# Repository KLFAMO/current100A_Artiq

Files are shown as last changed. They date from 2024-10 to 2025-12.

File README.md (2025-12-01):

# current100A_Artiq
100A current driver compatible with Artiq. At the moment, device is compatible with Sinara package size and includes all Sinara connectors. There is no software compatibility yet.

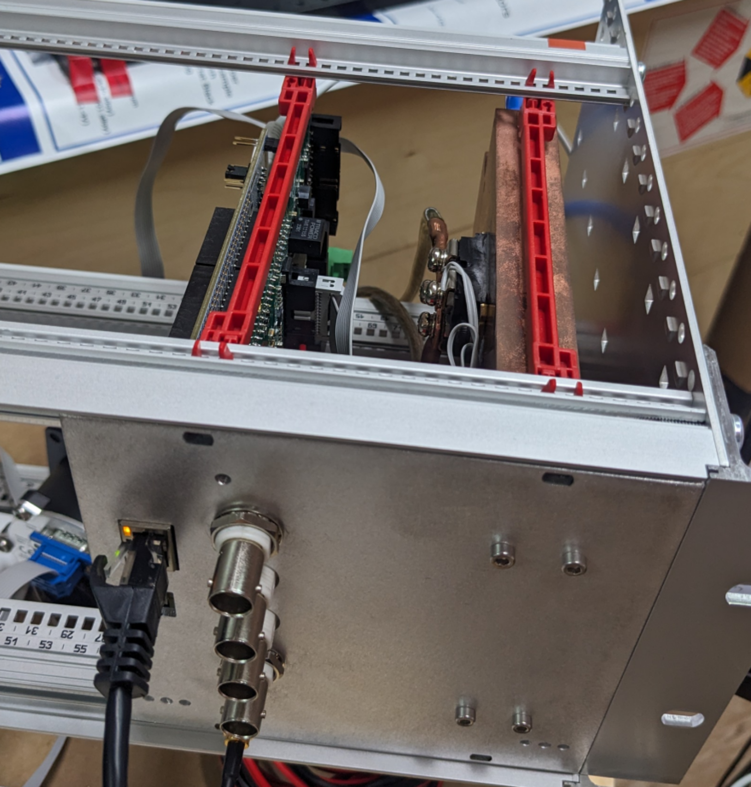
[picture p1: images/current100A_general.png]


## High power circuit

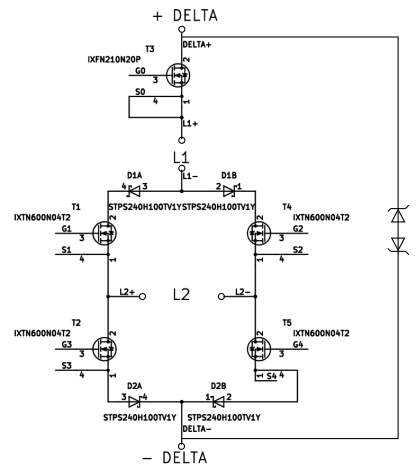
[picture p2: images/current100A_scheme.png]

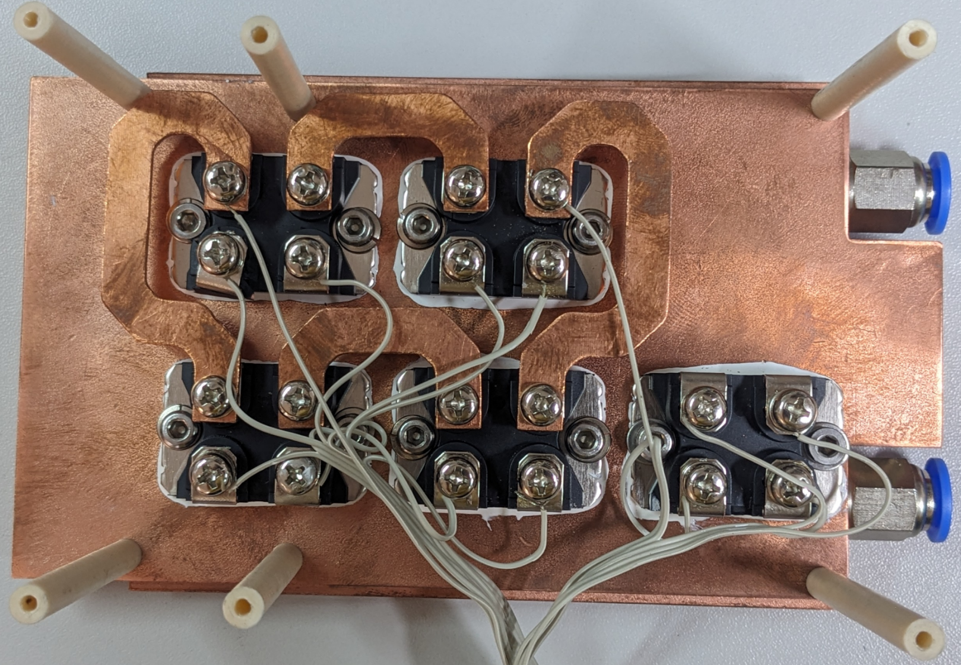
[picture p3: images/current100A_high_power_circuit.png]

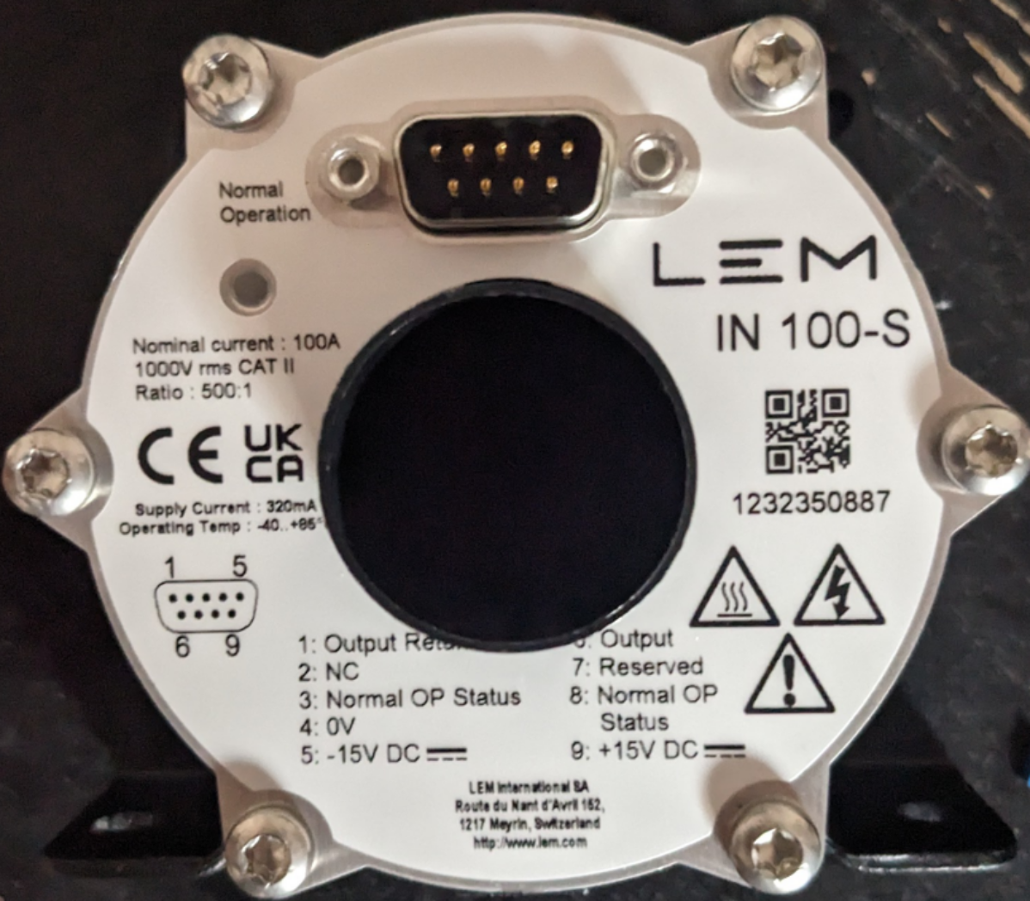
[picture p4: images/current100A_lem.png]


Power supply - two wires (+ and -) from Delta Power Supply. (will be WAGO connector asap).
Warning: 

Coil 1 (L1) - two wires from one coil (will be WAGO connector asap)

Coil 2 (L2) - two wires from second coil (this coil is direction switchable) (will be WAGO connector asap)

LEM IN 100-S is used for current measurement.

## Control board

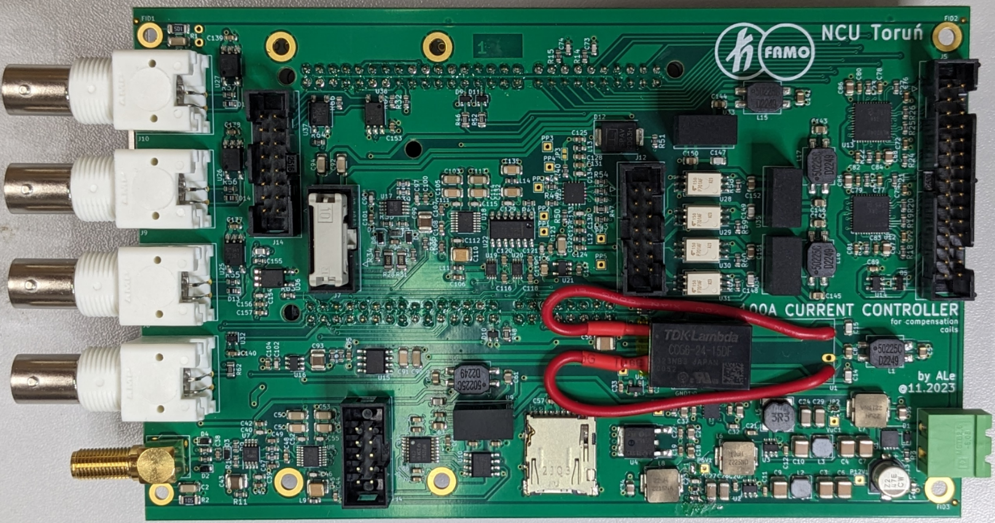
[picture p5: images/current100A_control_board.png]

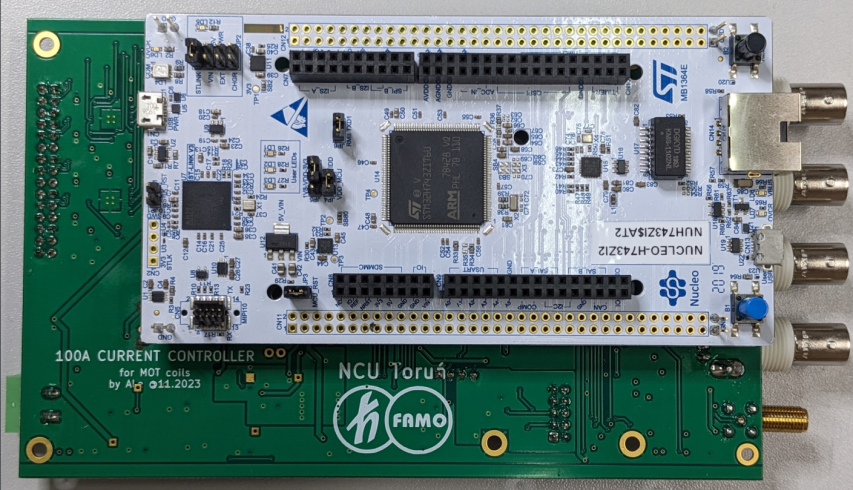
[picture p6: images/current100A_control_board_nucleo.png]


Power supply MSTBA green connector (0 and +12V) for control board.

Ethernet - User Interface communication.

SMA input - (-10V to +10V) current control by voltage (from external control program). 1V -> 10A

4x BNC inputs - not used yet

USB micro - not used yet

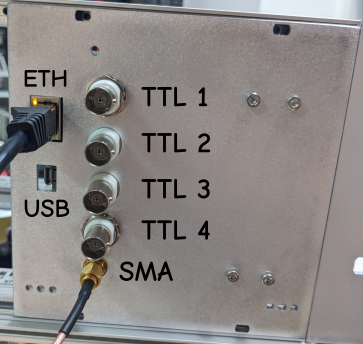
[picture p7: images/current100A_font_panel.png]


# User Interface

User interface is available via TCP/IP on port 10. Depending on configuration IP address is static or taken from DHCP - this must be set when programming uC. After connecting to the device user is able to change setting by sending commands.

## Commands
### Bbasic control

`MODE 0` - switch off current

`MODE 1` - current control via voltage input (SMA input on front panel)

`MODE 2` - current control via ethernet user interface (`CUR` command)

`CUR 10.2` - set current 10.2 A (only in mode 2)

`IMAX 25` - set max possible current value to 25A

`ERMAX 1` - max 1A change in each cycle (0.1ms)

### Advanced settings

`MODE 3` - set gate voltage using `VG` parameter

`I -0.04` - set gain -0.04 (this is bese gain for 50A - it is rescaled by uC for lower current due to udjust transistor characteristics)

`DIR x` - L2 coil current direction (x=-1: current positive, x=1: current negative, x=0: no current - all transistors blocked)

`DST x` - direction switching treshold; current direction switchin in coil L2 is possible only if absolute current value is less than x

`VG` - current gate voltage; in `MODE 3` is set manually

`CALIB 1` - gate voltage - current characteristics callibration. Improves current control.

`CALIB 4` - LEM zero current callibration (automaticaly done during startup)

## License

[MIT](https://opensource.org/licenses/MIT)

# Acknowledgments
This work has received funding from the European Partnership on Metrology, co-financed by the European Union’s Horizon Europe Research and Innovation Programme and by the Participating States, under grant number 22IEM01 TOCK.

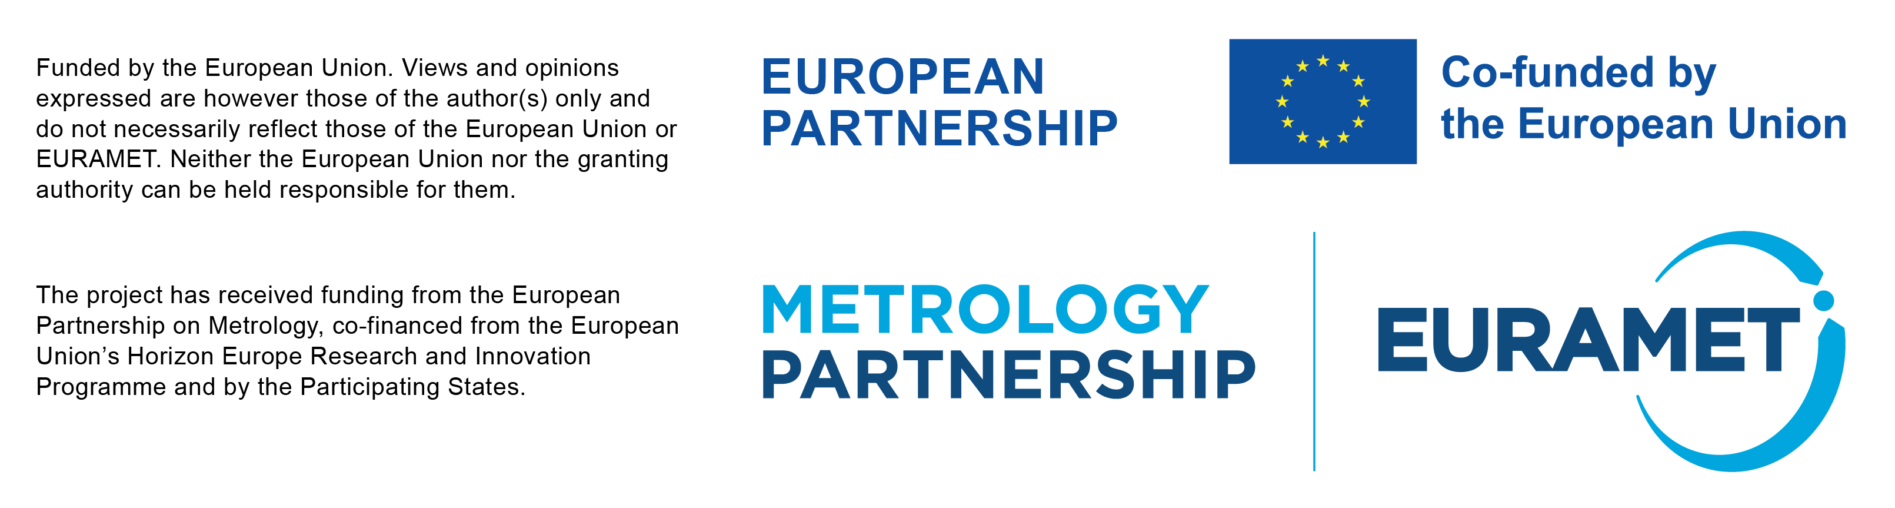
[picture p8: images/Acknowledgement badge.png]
badge


# Issues

Please add your comments in `Issues` Github section (in top of this website).

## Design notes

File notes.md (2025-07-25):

11-09-2024

Current fluctuates around +-10 mA (need to be explainded). On both, Power supply and LEM
V_set |     V_gate  |   I_power_sup |   I_lem_mA
3.130       3.11        0               4
3.180       3.16        0               5
3.270       3.15        0.005           12
3.4         3.38        0.027           33
3.6         3.57        0.180           182
3.7         3.67        0.415           410
3.8         3.77        0.912           880
3.9                     1.88            1820
4.0                     3.96            3376

27-09-2024

controller cycle = 2 ms
meas and sets = 1.17 ms  (TIM7: prescaler=80, period=2000)
for prescaler 80 -> period is measured in us.

single cnv measurement = 1us

changed cycle to 1ms
adc average 200
meas and sets time = 220us

23.10.2024
40A  -  I=-0.015 (ringing)
30A  -  I=-0.019 (ringing)
20A  -  I=-0.025 (ringing)
10A  -  I=-0.042 (ringing)
5A   -  I=-0.077 (ringing)
2A   -  I=-0.18  (ringing)

we set I = -0.01 for 40 A

15-12-2024
new high power circuit with diodes for tock

Vg - I characteristics
cur     vg
0       3.3997
0.5     4.063
1       4.168
1.5     4.234
2       4.283
2.5     4.323
3       4.358
3.5     4.390
4       4.4169
4.5     4.44
5       4.46
6       4.54
7       4.578
8       4.608
9       4.634

10      4.66
11      4.683
12      4.705
13      4.726
14      4.745
15      4.764
16      4.783
17      4.8
18      4.817
19      4.834

20      4.851
21      4.866
22      4.881
23      4.895
24      4.91
25      4.924

02-01-2025
working on shortening cycle time

mode 1 - 140us
mode 2 - 125us
mode 0 - 13us

full cycle set to 200us (before 300us)

switching directions coils using registers instead of hal
mode 1 - 140us
mode 2 - 125us
mode 0 - 13us

----
send_adc_cnvs(100);  - 90.1us
lema = [-0.3110286669, -0.3114823055, -0.3047171740,
-0.3088196444, -0.3112061777, -0.3090366020, -0.3105158581,
-0.3086224103, -0.309214112, -0.3132968597, -0.3124290294]

send_adc_cnvs(50);  - 45.3us
lema = [-0.3115611992, -0.3119162206, -0.3100030493,
-0.3078334736, -0.3146972222, -0.3097860918, -0.3074981756,
-0.3136321578, -0.3098649854, -0.3189180331, -0.3147366690,
-0.3090760488, -0.3099833259, -0.3111667308, -0.3101016664]

send_adc_cnvs(20);  - 18.4us
lema = [-0.3172218194, -0.3297461881, -0.3224485244,
-0.3268271227, -0.3197069697, -0.3215412473, -0.3188785863,
-0.3306337418, -0.3207523107, -0.3178726921, -0.3206536936]

setting send_adc_cnvs(25) -> 22.9us
mode 1 - 73us
mode 2 - 58us
mode 0 - 13us
changing cycle to 110us

----
reading SPI data from ADC
17us

optymalizacja funkcji czytającej (spi still in hal)  ->  15.2us
spi is more complicated to do without hal (I will try to change it later)
the same for adc_set

changed cycle to 100 us
mode 1 - 69.5us
mode 2 - 56us
mode 0 - 13us

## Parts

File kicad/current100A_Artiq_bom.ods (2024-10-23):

Source: | D:\Projekty\FAMO\current100A_Artiq\current100A_Artiq.kicad_sch
Date: | 28.11.2023 11:49:46
Tool: | Eeschema 7.0.1
Generator: | C:\Program Files\KiCad\bin\scripting\plugins/bom_csv_grouped_by_value.py
Component Count: | 311
Item | Qty | Reference(s) | Value | Footprint | Datasheet | Comm
1 | 43 | C11, C12, C19, C20, C21, C22, C30, C31, C33, C36, C57, C58, C60, C64, C65, C67, C68, C71, C72, C75, C76, C77, C78, C79, C80, C81, C82, C83, C84, C89, C116, C118, C120, C121, C130, C131, C136, C137, C138, C139, C140, C153, C156 | 100n 50V X7R | Capacitor_SMD:C_0603_1608Metric | ~
2 | 17 | C23, C39, C40, C46, C52, C55, C97, C98, C102, C111, C112, C115, C126, C129, C133, C134, C154 | 100p 50V C0G | Capacitor_SMD:C_0603_1608Metric | ~
3 | 6 | C38, C47, C49, C96, C107, C109 | 1n 50V C0G | Capacitor_SMD:C_0603_1608Metric | ~
4 | 2 | C73, C74 | 82p 50V C0G | Capacitor_SMD:C_0603_1608Metric | ~
5 | 14 | C41, C42, C44, C95, C100, C101, C104, C106, C117, C124, C125, C127, C128, C157 | GCM188R71E105KA64J | Capacitor_SMD:C_0603_1608Metric | ~ | 1uF 25V X7R
6 | 3 | C66, C69, C70 | GCM188R71E474KA64D | Capacitor_SMD:C_0603_1608Metric | ~ | 470n 25V X7R
7 | 1 | C32 | GRM1885C1H103JA01D | Capacitor_SMD:C_0603_1608Metric | ~ | 10n 50V C0G 5%
8 | 1 | C123 | GRM31C5C1H104JA01L | Capacitor_SMD:C_0603_1608Metric | ~ | 100n 50V C0G
9 | 2 | C48, C108 | 470p 50V C0G | Capacitor_SMD:C_0603_1608Metric_Pad1.08x0.95mm_HandSolder | ~
10 | 6 | C14, C15, C62, C147, C148, C149 | 1n C0G 100V | Capacitor_SMD:C_0805_2012Metric | ~
11 | 1 | C155 | 22n C0G 25V | Capacitor_SMD:C_0805_2012Metric | ~
12 | 1 | C119 | GCM21BR71C335KA73L | Capacitor_SMD:C_0805_2012Metric | ~ | 3,3u >10VDC X7R
13 | 20 | C5, C8, C16, C17, C18, C25, C26, C37, C59, C61, C63, C141, C142, C143, C144, C145, C146, C150, C151, C152 | GRM21BR61E106KA73L | Capacitor_SMD:C_0805_2012Metric | ~ | 10u 25V X5R
14 | 6 | C34, C35, C85, C86, C87, C88 | GRM21BR71A106KA73L | Capacitor_SMD:C_0805_2012Metric | ~ | 10u 10V X7R
15 | 2 | C1, C2 | GCJ31BR73A102KXJ1L | Capacitor_SMD:C_1206_3216Metric | ~
16 | 8 | C50, C53, C90, C92, C94, C103, C113, C122 | GCM31CR71C106KA64L | Capacitor_SMD:C_1206_3216Metric | ~ | 10u X7R 16VDC
17 | 7 | C51, C54, C91, C105, C114, C132, C135 | GRM31C5C1H104JA01L | Capacitor_SMD:C_1206_3216Metric | ~ | 100n 50V C0G
18 | 4 | C24, C27, C28, C29 | GRM31CR71A226KE15L | Capacitor_SMD:C_1206_3216Metric | ~ | 22u 10V X7R Murata
19 | 5 | C3, C4, C6, C7, C56 | 10u X7R 50V | Capacitor_SMD:C_1210_3225Metric | ~ | Murata GRM32ER71H106KA12L
20 | 2 | C45, C110 | 47UF 10V X7R | Capacitor_SMD:C_1210_3225Metric | ~ | 47UF 10V X7R
21 | 3 | C43, C93, C99 | C1210C334J3JACAUTO | Capacitor_SMD:C_1210_3225Metric | ~ | 330n U2J 25V
22 | 2 | C9, C10 | GCM32ER71E106KA57K | Capacitor_SMD:C_1210_3225Metric | ~ | 10u 25V X7R Murata
23 | 1 | C13 | UCW1E470MCL1GS | Capacitor_SMD:CP_Elec_6.3x7.7 |  | >=47u, >=20V, >=5000h, h<9mm
24 | 1 | J3 | DM3AT-SF-PEJM5 | Connector_Card:microSD_HC_Hirose_DM3AT-SF-PEJM5 | https://www.hirose.com/product/document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
25 | 4 | J8, J9, J10, J11 | 5227161-1 | Connector_Coaxial:BNC_Amphenol_B6252HB-NPP3G-50_Horizontal | ~ | 031-5431-10RFX
26 | 1 | J2 | RF2-49B-T-00-50-G-HDW | Connector_Coaxial:SMA_Amphenol_132203-12_Horizontal | ~
27 | 2 | J4, J7 | N2510-6002-RB | Connector_IDC:IDC-Header_2x05_P2.54mm_Vertical | ~
28 | 1 | J12 | N2514-6002RB | Connector_IDC:IDC-Header_2x07_P2.54mm_Vertical | ~
29 | 1 | J14 | N2516-6002-RB | Connector_IDC:IDC-Header_2x08_P2.54mm_Vertical | ~
30 | 1 | J5 | N2530-6002-RB | Connector_IDC:IDC-Header_2x15_P2.54mm_Vertical | ~
31 | 1 | J1 | MSTBA2.5/2-G-5.08 1757242 | Connector_Phoenix_MSTB:PhoenixContact_MSTBA_2,5_2-G-5,08_1x02_P5.08mm_Horizontal | ~
32 | 1 | J13 | L17DAFRA15S | Connectors_DSub:DSUB-15_Female_EdgeMount_Pitch2.77mm | ~ | nie montować, dostarczyć
33 | 1 | J6 | L17DEFRA09S | Connectors_DSub:DSUB-9_Female_EdgeMount_Pitch2.77mm | ~ | nie montować, dostarczyć
34 | 2 | D3, D7 | CZRU52C4V3 | Diode_SMD:D_0603_1608Metric
35 | 3 | D13, D14, D15 | TS4148C RZG | Diode_SMD:D_0603_1608Metric |  | TS4148 RCG
36 | 4 | D2, D4, D6, D8 | TSS40U-RGG | Diode_SMD:D_0603_1608Metric |  | CD0603-B0340R
37 | 1 | D12 | 5.0SMDJ12AS | Diode_SMD:D_SMC | ~
38 | 1 | D1 | SD12C-01FTG | Diode_SMD:D_SOD-323 | https://www.littelfuse.com/~/media/electronics/datasheets/tvs_diode_arrays/littelfuse_tvs_diode_array_sd_c_datasheet.pdf.pdf
39 | 1 | U9 | AM1SS-1203SJZ | ff_lib_7:AM1SS-xxxxS | https://www.aimtec.com/site/Aimtec/files/Datasheet/HighResolution/am1ss-jz.pdf
40 | 3 | U33, U34, U35 | TME1215S | ff_lib_7:AM1SS-xxxxS | https://www.tme.eu/Document/ecc45a2bcbf6e1314ca25a1f4efc1d56/TME-SERIES-EN.pdf
41 | 1 | Q1 | SISS27DN-T1-GE3 | ff_lib_7:Diodes_PowerDI3333-8 | https://www.diodes.com/assets/Datasheets/DMP3007SFG.pdf | SISA01DN-T1-GE3
42 | 5 | L1, L10, L15, L16, L17 | 50225C Murata | ff_lib_7:L_CommonMode_Murata_5000 | https://www.murata-ps.com/pub/data/magnetics/kmp_5000c.pdf | or 50475C
43 | 2 | L2, L3 | LQH44PH220MPRL | ff_lib_7:L_MURATA_LQH44 |  | 22u >0,5A 4x4mm
44 | 1 | M1 | DS1023-2*8S21 | ff_lib_7:MODULE_NUCLEO-F746ZG_mini_M
45 | 1 |  | DS1023-2*10S21
46 | 1 |  | DS1023-2*16S21
47 | 1 |  | DS1023-2*17S21
48 | 1 | U1 | CCG6-12-15DF | ff_lib_7:TDK_DCDC_CCG6_10 | https://product.tdk.com/system/files/dam/doc/product/power/switching-power/dc-dc-converter/catalog/ccg1r5_10_e.pdf | CCG6-24-15DF
49 | 1 | U6 | TPS7A3001DRBx | ff_lib_7:Texas_VSON-8_1EP_3x3mm_P0,65mm_vias | https://www.ti.com/lit/ds/symlink/tps7a30.pdf
50 | 2 | U12, U13 | SN65MLVD040RGZT | ff_lib_7:VQFN-48-1EP_7x7mm_P0.5mm_EP4.1x4.1mm_ThermalVias | https://www.ti.com/lit/ds/symlink/sn65mlvd040.pdf
51 | 1 | U23 | OPA4191xRUMx | ff_lib_7:WQFN-16-1EP_4x4mm_P0.65mm_EP2.7x2.7mm_ThermalVias | https://www.ti.com/lit/ds/symlink/opa4191.pdf
52 | 1 | L4 | BLM18KG331SN1D | Inductor_SMD:L_0603_1608Metric |  | Murata
53 | 5 | L9, L11, L12, L13, L14 | BLM18HE102SN1D | Inductor_SMD:L_0603_1608Metric |  | Murata
54 | 1 | L5 | SRN6045-3R3Y | Inductor_SMD:L_Bourns-SRN6028 |  | 3,3u >3A 6x6mm
55 | 1 | L6 | IHLP2525CZER100M01 | Inductor_SMD:L_Vishay_IHLP-2525 |  | 10u >3A 6,5x6,5mm
56 | 2 | L7, L8 | IHLP2525CZER220M11 | Inductor_SMD:L_Vishay_IHLP-2525 | https://www.vishay.com/docs/34104/ihlp-2525cz-01.pdf
57 | 5 | U25, U26, U27, U36, U38 | TLP2361(TPL,E | Package_SO:MFSOP6-5_4.4x3.6mm_P1.27mm | https://toshiba.semicon-storage.com/info/docget.jsp?did=14229&prodName=TLP2361
58 | 2 | U8, U18 | LTC2380CMS-24#PBF | Package_SO:MSOP-16_3x4mm_P0.5mm | https://www.analog.com/media/en/technical-documentation/data-sheets/238024fa.pdf
59 | 2 | U7, U17 | THS4561IDGKx | Package_SO:MSOP-8_3x3mm_P0.65mm | https://www.ti.com/lit/ds/symlink/ths4561.pdf | LTC1992xMS8#TRPBF, LTC6363xMS8#TRPBF
60 | 1 | U37 | TLP175A | Package_SO:SO-4_4.4x4.3mm_P2.54mm | https://toshiba.semicon-storage.com/info/docget.jsp?did=13665&prodName=TLP175A
61 | 1 | U22 | MAX5719AGSD+ | Package_SO:SOIC-14_3.9x8.7mm_P1.27mm | https://datasheets.maximintegrated.com/en/ds/MAX5717-MAX5719.pdf
62 | 1 | U15 | ADR4540BRZ | Package_SO:SOIC-8_3.9x4.9mm_P1.27mm | https://www.analog.com/media/en/technical-documentation/data-sheets/ADR4520_4525_4530_4533_4540_4550.pdf
63 | 1 | U10 | ADuM121N | Package_SO:SOIC-8_3.9x4.9mm_P1.27mm | https://www.analog.com/media/en/technical-documentation/data-sheets/ADuM120N_121N.pdf
64 | 4 | U28, U29, U30, U31 | TLP701AF(F) | Package_SO:SSO-6_6.8x4.6mm_P1.27mm_Clearance7mm | https://www.tme.eu/Document/18eec4fc8ccc3944788c5600a6539d11/TLP701AFF.pdf
65 | 1 | U11 | MAX3221ExPWR | Package_SO:TSSOP-16_4.4x5mm_P0.65mm | http://www.ti.com/lit/ds/symlink/max3221e.pdf
66 | 2 | U19, U20 | 74LVC2T45DC,125 | Package_SO:VSSOP-8_2.3x2mm_P0.5mm | https://assets.nexperia.com/documents/data-sheet/74LVC_LVCH2T45.pdf
67 | 1 | D5 | WE 8240136 | Package_TO_SOT_SMD:SOT-143 | https://assets.nexperia.com/documents/data-sheet/PRTR5V0U2X.pdf | PRTR5V0U2X
68 | 1 | U5 | AP7313-25SAG-7 | Package_TO_SOT_SMD:SOT-23 | https://www.tme.eu/Document/863c8cbcd42f90a36fcf1f70fe984947/AP7313.pdf
69 | 1 | U14 | 24AA02E48T-I/OT | Package_TO_SOT_SMD:SOT-23-5 | https://ww1.microchip.com/downloads/en/DeviceDoc/24AA02E48-24AA025E48-24AA02E64-24AA025E64-Data-Sheet-20002124H.pdf
70 | 1 | U21 | LP2981-50DBVR | Package_TO_SOT_SMD:SOT-23-5 | http://www.ti.com/lit/ds/symlink/lp2985.pdf
71 | 1 | U16 | ADA4895-1ARJZ | Package_TO_SOT_SMD:SOT-23-6 | https://www.analog.com/media/en/technical-documentation/data-sheets/ADA4807-1_4807-2_4807-4.pdf
72 | 3 | D9, D10, D11 | BAT54SW | Package_TO_SOT_SMD:SOT-323_SC-70 | https://assets.nexperia.com/documents/data-sheet/BAT54W_SER.pdf
73 | 1 | U32 | NL17SZ16DFT2G | Package_TO_SOT_SMD:SOT-353_SC-70-5 | http://www.ti.com/lit/sg/scyt129e/scyt129e.pdf
74 | 1 | U24 | NC7WZ17P6X | Package_TO_SOT_SMD:SOT-363_SC-70-6 | http://www.ti.com/lit/sg/scyt129e/scyt129e.pdf
75 | 1 | U4 | LD29150DT50R | Package_TO_SOT_SMD:TO-252-2 | https://www.st.com/content/ccc/resource/technical/document/datasheet/cc/41/70/73/f5/e6/40/50/CD00003403.pdf/files/CD00003403.pdf/jcr:content/translations/en.C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
76 | 1 | U2 | AP63200WU-7 | Package_TO_SOT_SMD:TSOT-23-6 | https://www.diodes.com/assets/Datasheets/AP63200-AP63201-AP63203-AP63205.pdf
77 | 1 | U3 | AP63203WU-7 | Package_TO_SOT_SMD:TSOT-23-6 | https://www.diodes.com/assets/Datasheets/AP63200-AP63201-AP63203-AP63205.pdf
78 | 12 | R16, R17, R18, R19, R20, R21, R22, R23, R24, R25, R26, R27 | 100R 1% | Resistor_SMD:R_0603_1608Metric | ~
79 | 2 | R29, R30 | 10k 0,1% 10ppm | Resistor_SMD:R_0603_1608Metric | ~ | ERA-3ARB103V, RN73H1JTTD1002B10, RQ73C1J10KBTDF
80 | 4 | R3, R6, R44, R51, R65 | 10k 1% | Resistor_SMD:R_0603_1608Metric | ~
81 | 4 | R58, R59, R60, R61 | 150R 1% | Resistor_SMD:R_0603_1608Metric | ~
82 | 2 | R4, R5 | 196k 1% | Resistor_SMD:R_0603_1608Metric | ~
83 | 16 | R11, R32, R35, R40, R41, R43, R45, R49, R53, R54, R55, R56, R57, R63, R64, R67 | 1k 1% | Resistor_SMD:R_0603_1608Metric | ~
84 | 2 | R14, R15 | 220R 1% | Resistor_SMD:R_0603_1608Metric | ~
85 | 4 | R9, R10, R36, R37 | 2k 1% | Resistor_SMD:R_0603_1608Metric | ~
86 | 1 | R66 | 2k4 1% | Resistor_SMD:R_0603_1608Metric | ~
87 | 4 | R7, R8, R33, R34 | 4,99k 1% | Resistor_SMD:R_0603_1608Metric | ~
88 | 4 | R12, R13, R38, R39 | 49,9R 1% | Resistor_SMD:R_0603_1608Metric | ~
89 | 1 | R50 | 910R 1% | Resistor_SMD:R_0603_1608Metric | ~
90 | 0 | R42 | DNP | Resistor_SMD:R_0603_1608Metric | ~
91 | 5 | R46, R47, R48, R52, R62 | 100R 1% | Resistor_SMD:R_0805_2012Metric | ~
92 | 2 | R1, R2 | HV732BTTD1004F | Resistor_SMD:R_1206_3216Metric | ~
93 | 2 | R28, R31 | RQ73C2B20RBTD | Resistor_SMD:R_1206_3216Metric | ~ | 20R 0,1% 10ppm 0,4W, 3-2176383-0

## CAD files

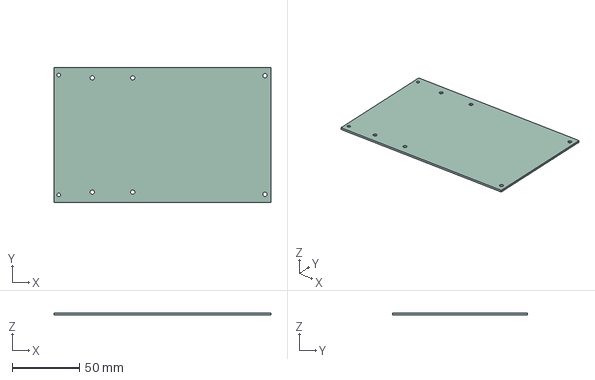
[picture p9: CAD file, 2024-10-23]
kicad/model/artiq_base.step
161.0 x 100.0 x 1.58 mm

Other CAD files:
kicad/model/artiq_base.FCStd

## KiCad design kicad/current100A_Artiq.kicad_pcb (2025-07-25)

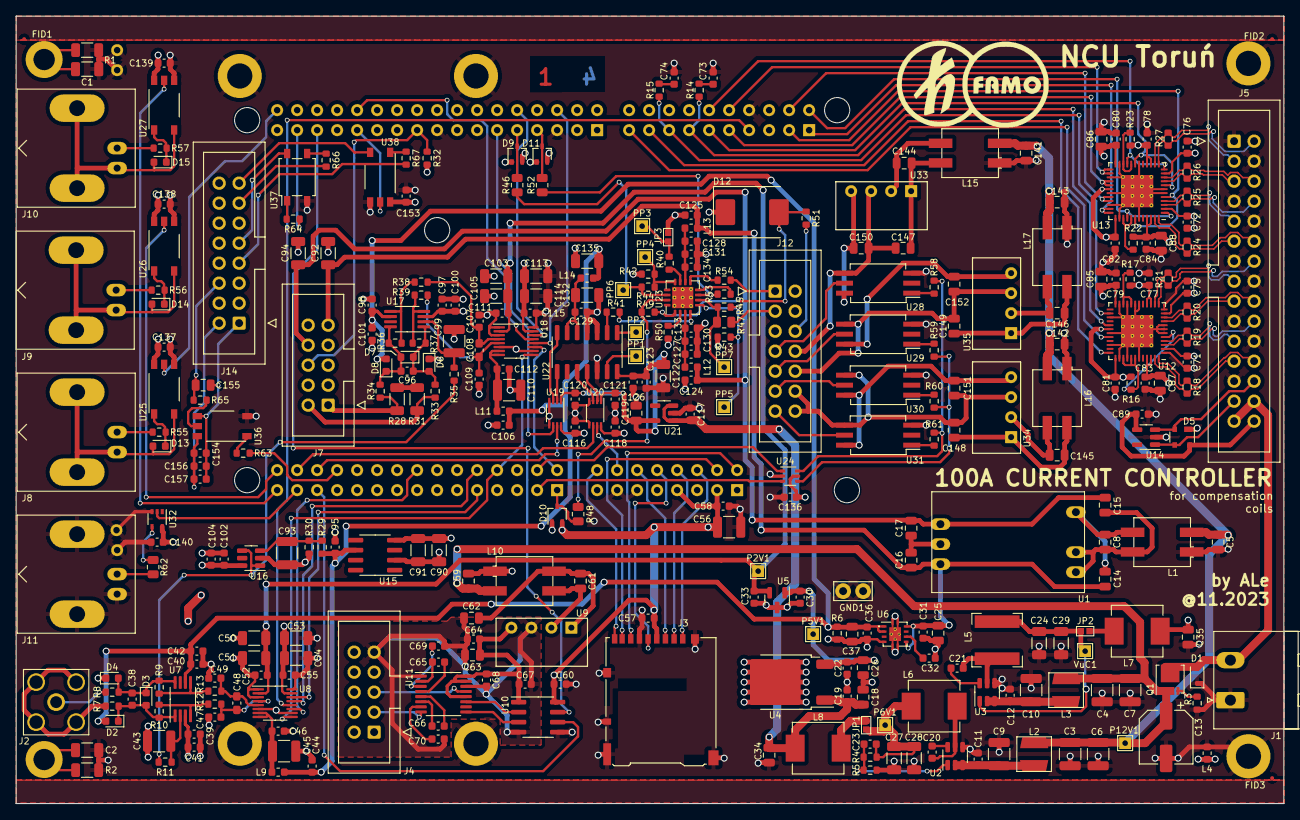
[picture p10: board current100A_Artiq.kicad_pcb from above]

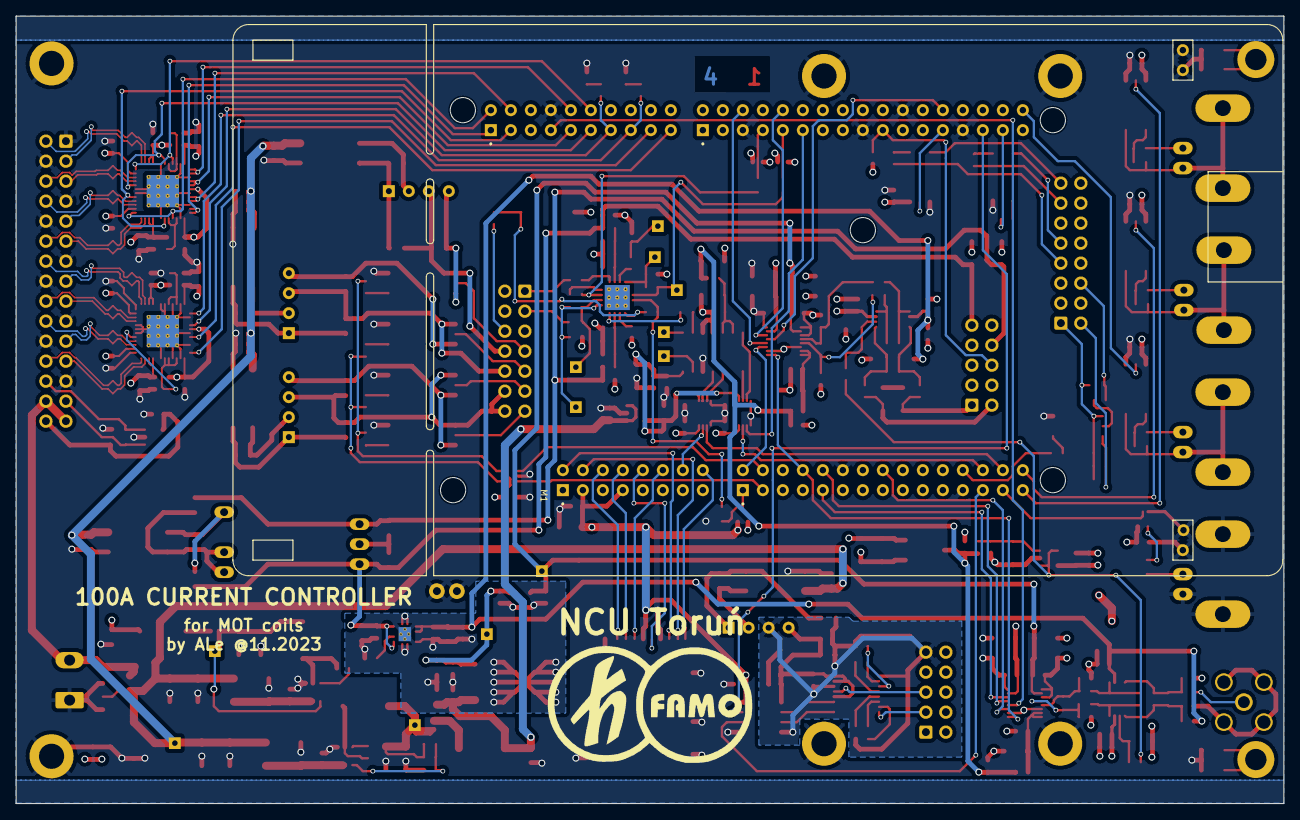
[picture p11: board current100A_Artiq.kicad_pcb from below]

Board: 4 copper layers, 161.0 x 100.0 mm, 337 parts (2 on the bottom side), 210 nets.

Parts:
C1, C2: GCJ31BR73A102KXJ1L; C_1206_3216Metric
C3, C4, C6, C7, C56: 10u X7R 50V; C_1210_3225Metric
C5, C8, C16, C17, C18, C25, C26, C37, C59, C61, C63, C141, C142, C143, C144, C145, C146, C150, C151, C152: GRM21BR61E106KA73L; C_0805_2012Metric
C9, C10: GCM32ER71E106KA57K; C_1210_3225Metric
C11, C12, C19, C20, C21, C22, C30, C31, C33, C36, C57, C58, C60, C64, C65, C67, C68, C71, C72, C75, C76, C77, C78, C79, C80, C81, C82, C83, C84, C89, C116, C118, C120, C121, C130, C131, C136, C137, C138, C139, C140, C153, C156: 100n 50V X7R; C_0603_1608Metric
C13: UCW1E470MCL1GS; CP_Elec_6.3x7.7
C14, C15, C62, C147, C148, C149: 1n C0G 100V; C_0805_2012Metric
C23, C39, C40, C46, C52, C55, C97, C98, C102, C111, C112, C126, C129, C133, C134, C154: 100p 50V C0G; C_0603_1608Metric
C24, C27, C28, C29: GRM31CR71A226KE15L; C_1206_3216Metric
C32: GRM1885C1H103JA01D; C_0603_1608Metric
C34, C35, C85, C86, C87, C88: GRM21BR71A106KA73L; C_0805_2012Metric
C38, C47, C49, C96, C107, C109: 1n 50V C0G; C_0603_1608Metric
C41, C42, C44, C95, C100, C101, C104, C106, C117, C124, C125, C127, C128, C157: GCM188R71E105KA64J; C_0603_1608Metric
C43, C93, C99: C1210C334J3JACAUTO; C_1210_3225Metric
C45, C110: 47UF 10V X7R; C_1210_3225Metric
C48, C108: 470p 50V C0G; C_0603_1608Metric_Pad1.08x0.95mm_HandSolder
C50, C53, C90, C92, C94, C103, C113, C122: GCM31CR71C106KA64L; C_1206_3216Metric
C51, C54, C91, C105, C114, C132, C135: GRM31C5C1H104JA01L; C_1206_3216Metric
C66, C69, C70: GCM188R71E474KA64D; C_0603_1608Metric
C73, C74: 82p 50V C0G; C_0603_1608Metric
C115: 100p C0G 50V; C_0603_1608Metric
C119: GCM21BR71C335KA73L; C_0805_2012Metric
C123: GRM31C5C1H104JA01L; C_0603_1608Metric
C155: 22n C0G 25V; C_0805_2012Metric
D1: SD12C-01FTG; D_SOD-323
D2, D4, D6, D8: TSS40U-RGG; D_0603_1608Metric
D3, D7: CZRU52C4V3; D_0603_1608Metric
D5: WE 8240136; SOT-143
D9, D10, D11: BAT54SW; SOT-323_SC-70
D12: 5.0SMDJ12AS; D_SMC
D13, D14, D15: TS4148C RZG; D_0603_1608Metric
FID1, FID2, FID3: Fiducial; Fiducial_0.5mm_Mask1.5mm
G1: KL_FAMO_LOGO; kl_famo_logo
G2: KL_FAMO_LOGO; kl_famo_logo_small
GND1: PAD; TestPoint_Bridge_Pitch2.54mm_Drill1.0mm
H1, H2: MountingHole_Pad; MountingHole_2.7mm_M2.5_DIN965_Pad
H3, H4, H5, H6, H7, H8: MountingHole_Pad; MountingHole_3.2mm_M3_DIN965_Pad
J1: MSTBA2.5/2-G-5.08 1757242; PhoenixContact_MSTBA_2,5_2-G-5,08_1x02_P5.08mm_Horizontal
J2: RF2-49B-T-00-50-G-HDW; SMA_Amphenol_132203-12_Horizontal
J3: DM3AT-SF-PEJM5; microSD_HC_Hirose_DM3AT-SF-PEJM5
J4, J7: N2510-6002-RB; IDC-Header_2x05_P2.54mm_Vertical
J5: N2530-6002-RB; IDC-Header_2x15_P2.54mm_Vertical
J8: B6252H5-NPP3G-50; BNC_Amphenol_B6252HB-NPP3G-50_Horizontal
J9, J10, J11: 5227161-1; BNC_Amphenol_B6252HB-NPP3G-50_Horizontal
J12: N2514-6002RB; IDC-Header_2x07_P2.54mm_Vertical
J14: N2516-6002-RB; IDC-Header_2x08_P2.54mm_Vertical
JP1, JP2: Jumper_NO_Small; GS2_small
JP3: Jumper_2_Bridged; GS2_small
L1, L10, L15, L16, L17: 50225C Murata; L_CommonMode_Murata_5000
L2, L3: LQH44PH220MPRL; L_MURATA_LQH44
L4: BLM18KG331SN1D; L_0603_1608Metric
L5: SRN6045-3R3Y; L_Bourns-SRN6028
L6: IHLP2525CZER100M01; L_Vishay_IHLP-2525
L7, L8: IHLP2525CZER220M11; L_Vishay_IHLP-2525
L9, L11, L12, L13, L14: BLM18HE102SN1D; L_0603_1608Metric
M1: NUCLEO-H743ZI; MODULE_NUCLEO-F746ZG_mini_M
P2V1, P5V1, P6V1, P12V1: TestPoint; TestPoint_THTPad_1.5x1.5mm_Drill0.7mm
PP1, PP2, PP3, PP4, PP5, PP6, PP7: PAD; TestPoint_THTPad_1.5x1.5mm_Drill0.7mm
Q1: SISS27DN-T1-GE3; Diodes_PowerDI3333-8
R1, R2: HV732BTTD1004F; R_1206_3216Metric
R3, R6, R44, R51, R65: 10k 1%; R_0603_1608Metric
R4, R5: 196k 1%; R_0603_1608Metric
R7, R8, R33, R34: 4,99k 1%; R_0603_1608Metric
R9, R10, R36, R37: 2k 1%; R_0603_1608Metric
R11, R32, R35, R40, R41, R43, R45, R49, R53, R54, R55, R56, R57, R63, R64, R67: 1k 1%; R_0603_1608Metric
R12, R13, R38, R39: 49,9R 1%; R_0603_1608Metric
R14, R15: 220R 1%; R_0603_1608Metric
R16, R17, R18, R19, R20, R21, R22, R23, R24, R25, R26, R27: 100R 1%; R_0603_1608Metric
R28, R31: RQ73C2B20RBTD; R_1206_3216Metric
R29, R30: 10k 0,1% 10ppm; R_0603_1608Metric
R42: DNP; R_0603_1608Metric
R46, R47, R48, R52: 100R 1%; R_0805_2012Metric
R50: 910R 1%; R_0603_1608Metric
R58, R59, R60, R61: 150R 1%; R_0603_1608Metric
R62: 100R; R_0805_2012Metric
R66: 2k4 1%; R_0603_1608Metric
U1: TME1215S; TDK_DCDC_CCG6_10
U2: AP63200WU-7; TSOT-23-6
U3: AP63203WU-7; TSOT-23-6
U4: LD29150DT50R; TO-252-2
U5: AP7313-25SAG-7; SOT-23
U6: TPS7A3001DRBx; Texas_VSON-8_1EP_3x3mm_P0,65mm_vias
U7, U17: THS4561IDGKx; MSOP-8_3x3mm_P0.65mm
U8, U18: LTC2380CMS-24#PBF; MSOP-16_3x4mm_P0.5mm
U9: AM1SS-1203SJZ; AM1SS-xxxxS
U10: ADuM121N; SOIC-8_3.9x4.9mm_P1.27mm
U11: MAX3221ExPWR; TSSOP-16_4.4x5mm_P0.65mm
U12, U13: SN65MLVD040RGZT; VQFN-48-1EP_7x7mm_P0.5mm_EP4.1x4.1mm_ThermalVias
U14: 24AA02E48T-I/OT; SOT-23-5
U15: ADR4540BRZ; SOIC-8_3.9x4.9mm_P1.27mm
U16: ADA4895-1ARJZ; SOT-23-6
U19, U20: 74LVC2T45DC,125; VSSOP-8_2.3x2mm_P0.5mm
U21: LP2981-50DBVR; SOT-23-5
U22: MAX5719AGSD+; SOIC-14_3.9x8.7mm_P1.27mm
U23: OPA4191xRUMx; WQFN-16-1EP_4x4mm_P0.65mm_EP2.7x2.7mm_ThermalVias
U24: NC7WZ17P6X; SOT-363_SC-70-6
U25, U26, U27, U36, U38: TLP2361(TPL,E; MFSOP6-5_4.4x3.6mm_P1.27mm
U28, U29, U30, U31: TLP701AF(F); SSO-6_6.8x4.6mm_P1.27mm_Clearance7mm
U32: NL17SZ16DFT2G; SOT-353_SC-70-5
U33, U34, U35: TME1215S; AM1SS-xxxxS
U37: TLP175A; SO-4_4.4x4.3mm_P2.54mm
VuC1: TestPoint; TestPoint_THTPad_1.5x1.5mm_Drill0.7mm

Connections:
+2V5: C33.2, C50.1, C51.2, C52.1, C103.1, C105.2, C111.1, P2V1.1, U5.2 (VO), U8.2 (VDD), U18.2 (VDD)
+3V3: C35.1, C53.1, C54.2, C55.1, C56.1, C57.1, C58.1, C60.2, C71.1, C72.1, C75.1, C76.1, C77.1, C78.1, C79.1, C80.1, C81.1, C82.1, C83.1, C84.1, C85.1, C86.1, C87.1, C88.1, C113.1, C114.2, C115.1, C116.2, C118.2, C136.1, C137.1, C138.1, C139.1, C140.1, C153.1, D9.2 (K), D10.2 (K), D11.2 (K), J3.4 (VDD), L7.1, M1.CN8_3 (IOREF_CN8), M1.CN8_7 (+3V3_CN8), R16.2, R17.2, R22.2, R23.2, R32.1, U8.15 (OVDD), U10.8 (VDD2), U12.2 (VCC), U12.11 (VCC), U12.15 (VCC), U12.16 (VCC), U12.24 (VCC), U12.30 (PDN), U12.37 (VCC), U12.45 (VCC), U12.46 (VCC), U13.2 (VCC), U13.11 (VCC), U13.15 (VCC), U13.16 (VCC), U13.24 (VCC), U13.30 (PDN), U13.37 (VCC), U13.45 (VCC), U13.46 (VCC), U18.15 (OVDD), U19.8 (VCCB), U20.8 (VCCB), U24.5 (V+), U25.6 (VCC), U26.6 (VCC), U27.6 (VCC), U32.5 (V+), U38.6 (VCC)
+4V: C44.1, C95.1, C106.1, C135.1, L9.1, L11.1, L14.1, R29.1, U15.6 (VOUT)
+5VA: C22.2, C26.1, C30.2, C39.1, C41.1, C90.1, C91.2, C97.1, C100.1, C102.1, C104.1, D4.1 (K), D6.1 (K), P5V1.1, U4.3 (OUT), U5.1 (VI), U7.3 (V+), U15.2 (VIN), U16.6 (V+), U17.3 (V+)
+5VD: C119.1, C120.2, C121.2, C122.1, C123.2, C126.1, U19.1 (VCCA), U20.1 (VCCA), U21.5 (VOUT), U22.14 (VDD)
+6V: C18.1, C19.2, C34.1, C117.1, L8.1, U4.1 (INP), U21.1 (VIN), U21.3 (ON/~OFF)
+12V: C3.1, C4.1, C5.1, C6.1, C7.1, C13.1, C59.1, C141.1, C142.1, C143.1, L1.2, L2.2, L3.2, L10.2, L15.2, L16.2, L17.2, P12V1.1, Q1.1 (S), Q1.2 (S), Q1.3 (S)
+15V: C15.1, C17.2, C94.1, C124.1, J7.8, L12.2, U1.4 (+VOUT)
-15V: C14.1, C16.1, C25.1, C31.1, C92.1, C125.1, J7.9, L13.2, U1.6 (-VOUT), U6.5 (EN), U6.8 (IN)
-VSW: C36.1, C37.1, C40.2, C42.2, C98.2, C101.2, D2.2 (A), D8.2 (A), R6.1, U6.1 (OUT), U6.2 (FB), U7.6 (V-), U17.6 (V-)
/15A_ON: M1.CN9_30 (D64/PG1/IO), U26.5 (VO)
/100A_ON: M1.CN9_29 (D65/PG0/IO), U27.5 (VO)
/ADC_CNV: M1.CN9_8 (D54/PD4/USART_B_RTS), U8.9 (CNV), U18.9 (CNV)
/AUX_SPAN: D9.3 (COM), M1.CN10_9 (A7/PF5/ADC3_IN4), R46.2
/Analog input1/ADC1INM: R9.2, R13.2, U7.5 (-)
/Analog input1/ADC1INP: R10.2, R12.2, U7.4 (+)
/Analog input1/IN_gnd: J2.2 (Ext), R7.1
/Analog input1/VREFB: C45.1, C46.1, L9.2, U8.7 (REF), U8.8 (REF/*DGC)
/Analog input1/VREF_P: R11.2, R35.2, U16.1, U16.4 (-)
/COIL_SPAN: D10.3 (COM), M1.CN9_1 (A0/PA3/ADC123_IN3), R48.2
/DEL_CC: M1.CN10_25 (D31/PE2/QSPI_BK1_IO2), U38.5 (VO)
/DEL_PWM: M1.CN9_24 (D61/PF8/SAI_B_SCK), R63.2
/DEL_RSD: M1.CN10_31 (XD33/PB0/TIMER_D_PWM1), R64.2
/DIR_L2: M1.CN10_34 (D35/PB11/TIMER_C_PWM3), U25.5 (VO)
/Digital inputs/output1/12V_pom4: C144.1, L15.3, U33.2 (+VIN)
/Digital inputs/output1/12V_pom5: C145.1, L16.3, U34.2 (+VIN)
/Digital inputs/output1/12V_pom6: C146.1, L17.3, U35.2 (+VIN)
/Digital inputs/output1/GT1: J12.7, U28.5 (VO)
/Digital inputs/output1/GT2: J12.9, U29.5 (VO)
/Digital inputs/output1/GT3: J12.11, U30.5 (VO)
/Digital inputs/output1/GT4: J12.13, U31.5 (VO)
/Digital inputs/output1/L2_LEFTB: R58.2, R61.2, U24.6
/Digital inputs/output1/L2_RIGHTB: R59.2, R60.2, U24.4
/Digital inputs/output1/ST1: C147.1, C150.2, J12.8, U28.4 (VEE), U33.3 (-VOUT)
/Digital inputs/output1/ST2: C149.1, C152.2, J12.10, U29.4 (VEE), U35.3 (-VOUT)
/Digital inputs/output1/ST3: C148.1, C151.2, J12.12, J12.14, U30.4 (VEE), U31.4 (VEE), U34.3 (-VOUT)
/Digital inputs/output1/VT1: C150.1, U28.6 (VCC), U33.4 (+VOUT)
/Digital inputs/output1/VT2: C152.1, U29.6 (VCC), U35.4 (+VOUT)
/Digital inputs/output1/VT3: C151.1, U30.6 (VCC), U31.6 (VCC), U34.4 (+VOUT)
/Digital inputs/output1/gnd_pom4: C144.2, C147.2, L15.4, U33.1 (-VIN)
/Digital inputs/output1/gnd_pom5: C145.2, C148.2, L16.4, U34.1 (-VIN)
/Digital inputs/output1/gnd_pom6: C146.2, C149.2, L17.4, U35.1 (-VIN)
/Kasli interface/I2C_SCL: D5.3 (I/O2), J5.27, U14.1 (SCL)
/Kasli interface/I2C_SDA: D5.2 (I/O1), J5.26, U14.3 (SDA)
/Kasli interface/LVDS0_N: J5.3, R27.1, U13.14 (4B)
/Kasli interface/LVDS0_P: J5.2, R27.2, U13.13 (4A)
/Kasli interface/LVDS1_N: J5.6, R26.1, U13.10 (3B)
/Kasli interface/LVDS1_P: J5.5, R26.2, U13.9 (3A)
/Kasli interface/LVDS2_N: J5.9, R25.1, U13.4 (2B)
/Kasli interface/LVDS2_P: J5.8, R25.2, U13.3 (2A)
/Kasli interface/LVDS3_N: J5.12, R24.1, U13.48 (1B)
/Kasli interface/LVDS3_P: J5.11, R24.2, U13.47 (1A)
/Kasli interface/LVDS4_N: J5.15, R21.1, U12.14 (4B)
/Kasli interface/LVDS4_P: J5.14, R21.2, U12.13 (4A)
/Kasli interface/LVDS5_N: J5.18, R20.1, U12.10 (3B)
/Kasli interface/LVDS5_P: J5.17, R20.2, U12.9 (3A)
/Kasli interface/LVDS6_N: J5.21, R19.1, U12.4 (2B)
/Kasli interface/LVDS6_P: J5.20, R19.2, U12.3 (2A)
/Kasli interface/LVDS7_N: J5.24, R18.1, U12.48 (1B)
/Kasli interface/LVDS7_P: J5.23, R18.2, U12.47 (1A)
/Kasli interface/P3V3_MP: C89.1, D5.4 (VCC), J5.30, U14.4 (V_{CC})
/L2_LEFT: M1.CN9_4 (D52/PD6/USART_B_RX), U24.1
/L2_RIGHT: M1.CN9_3 (A1/PC0/ADC123_IN10), U24.3
/LEM_ADC: M1.CN10_10 (D3/PE13/TIMER_A_PWM3), U18.14 (SDO)
/LEM_BUSY: M1.CN9_2 (D51/PD7/USART_B_SCLK), U18.11 (BUSY)
/LEM_OK: J7.6, M1.CN10_19 (D28/PD13/QSPI_BK1_IO3), R32.2
/LEM_RDL: M1.CN10_6 (D5/PE11/TIMER_A_PWM2), U18.12 (RDL/SDI)
/LEM_SCK: M1.CN10_26 (D39/PE12/TIMER_A_PWM3N), U18.13 (SCK)
/MOS_CLK: M1.CN9_26 (D62/PF7/SAI_B_MCLK), U19.7 (1B)
/MOS_CS: M1.CN10_11 (A8/PF6/ADC3_IN8), U19.6 (2B)
/MOS_DATA: M1.CN9_28 (D63/PF9/SAI_B_FS), U20.6 (2B)
/MOS_LDAC: M1.CN8_14 (D49/PG2/IO), U20.7 (1B)
/Main Current sensor1/ADC1INM: R37.2, R39.2, U17.4 (+)
/Main Current sensor1/ADC1INP: R36.2, R38.2, U17.5 (-)
/Main Current sensor1/LEM_c: R28.2, R31.1
/Main Current sensor1/LEM_out1: J7.1, R28.1, R34.1
/Main Current sensor1/LEM_out2: J7.2, R31.2, R33.1
/Main Current sensor1/VREFA: C110.1, C112.1, L11.2, U18.7 (REF), U18.8 (REF/*DGC)
/Nucleo-H743ZI1/SCPI_RX: M1.CN9_25 (D67/PD0/CAN_RX), U10.6 (VOB)
/Nucleo-H743ZI1/SCPI_TX: M1.CN10_29 (D32/PA0/TIMER_C_PWM1), U10.7 (VIA)
/Nucleo-H743ZI1/SCPI_interface/12V_pom3: C61.1, L10.3, U9.2 (+VIN)
/Nucleo-H743ZI1/SCPI_interface/VDISO: C63.1, C64.2, C67.2, C68.2, U9.4 (+VOUT), U10.1 (VDD1), U11.12 (FORCEON), U11.15 (VCC), U11.16 (~FORCEOFF)
/Nucleo-H743ZI1/SCPI_interface/VSISO: C62.1, C63.2, C64.1, C67.1, C68.1, C69.1, C70.1, J4.9, U9.3 (-VOUT), U10.4 (GND1), U11.1 (~EN), U11.14 (GND)
/Nucleo-H743ZI1/SCPI_interface/gnd_pom3: C61.2, C62.2, L10.4, U9.1 (-VIN)
/Nucleo-H743ZI1/SD_CK: J3.5 (CLK), M1.CN8_10 (D47/PC12/SDMMC_CK)
/Nucleo-H743ZI1/SD_CMD: J3.3 (CMD), M1.CN8_12 (D48/PD2/SDMMC_CMD)
/Nucleo-H743ZI1/SD_D0: J3.7 (DAT0), M1.CN8_2 (D43/PC8/SDMMC_D0)
/Nucleo-H743ZI1/SD_D1: J3.8 (DAT1), M1.CN8_4 (D44/PC9/SDMMC_D1/I2S_A_CKIN)
/Nucleo-H743ZI1/SD_D2: J3.1 (DAT2), M1.CN8_6 (D45/PC10/SDMMC_D2)
/Nucleo-H743ZI1/SD_D3: J3.2 (DAT3/CD), M1.CN8_8 (D46/PC11/SDMMC_D3)
/Nucleo-H743ZI1/SD_DET: J3.9 (DET_B), M1.CN8_16 (D50/PG3/IO)
/Power grid generation1/3V_out: JP2.1, L7.2
/Power grid generation1/6V_out: JP1.1, L8.2
/Power grid generation1/12V_pom: C10.1, C12.1, L3.1, U3.2 (EN), U3.3 (IN)
/Power grid generation1/12V_pom1: C9.1, C11.1, L2.1, U2.2 (EN), U2.3 (IN)
/Power grid generation1/12V_pom2: C8.1, C14.2, L1.3, U1.3 (+VIN)
/Power grid generation1/gnd_pom: C8.2, C15.2, L1.4, U1.1 (-VIN), U1.2 (RC)
/Power grid generation1/sw_out: C24.1, C29.1, JP2.2, L5.1, U3.1 (FB), VuC1.1
/Power grid generation1/sw_out1: C23.1, C27.1, C28.1, JP1.2, L6.1, P6V1.1, R4.1
/Power grid generation1/switch: C21.1, L5.2, U3.5 (SW)
/Power grid generation1/switch1: C20.1, L6.2, U2.5 (SW)
/SET_ADC: M1.CN9_9 (A4/PC2(PB9)/ADC3_IN12/I2C1_SDA), U8.14 (SDO)
/SET_BUSY: M1.CN9_16 (D57/PE4/SAI_A_FS), U8.11 (BUSY)
/SET_RDL: M1.CN7_7 (D19/PB12/I2S_A_WS), U8.12 (RDL/SDI)
/SET_SCK: M1.CN9_10 (D55/PD3/USART_B_CTS), U8.13 (SCK)
/T0_SPAN: D11.3 (COM), M1.CN10_7 (A6/PF4/ADC3_IN9), R52.2
/TO_C15A: M1.CN9_27 (D66/PD1/CAN_TX), U32.2
DAT4: M1.CN7_10 (D13/PA5/SPI_A_SCK), U13.25 (4D), U13.26 (4R)
DAT4_OUT: M1.CN7_12 (D12/PA6/SPI_A_MISO), U13.12 (4DE), U13.21 (~4RE)
DAT5: M1.CN7_9 (XD20/PA15/I2S_B_WS), U13.28 (3D), U13.29 (3R)
DAT5_OUT: M1.CN7_11 (D21/PC7/I2S_B_MCK), U13.8 (3DE), U13.19 (~3RE)
DAT6: M1.CN7_4 (D14/PB9/I2C_A_SDA), U13.32 (2D), U13.33 (2R)
DAT6_OUT: M1.CN7_3 (D17/PB15/I2S_A_SD), U13.5 (2DE), U13.42 (~2RE)
DAT7: M1.CN7_1 (D16/PC6/I2S_A_MCK), U13.35 (1D), U13.36 (1R)
DAT7_OUT: M1.CN7_2 (D15/PB8/I2C_A_SCL), U13.1 (1DE), U13.40 (~1RE)
DT0: J12.1, R54.2
GND: C1.2, C2.2, C3.2, C4.2, C5.2, C6.2, C7.2, C9.2, C10.2, C11.2, C12.2, C13.2, C24.2, C27.2, C28.2, C29.2, C34.2, C35.2, C53.2, C54.1, C55.2, C56.2, C57.2, C58.2, C59.2, C60.1, C71.2, C72.2, C73.2, C74.2, C75.2, C76.2, C77.2, C78.2, C79.2, C80.2, C81.2, C82.2, C83.2, C84.2, C85.2, C86.2, C87.2, C88.2, C89.2, C113.2, C114.1, C115.2, C116.1, C117.2, C118.1, C119.2, C120.1, C121.1, C122.2, C123.1, C126.2, C136.2, C137.2, C138.2, C139.2, C140.2, C141.2, C142.2, C143.2, C153.2, D1.1 (A1), D5.1 (GND), GND1.1, H3.1, H4.1, H5.1, H6.1, H7.1, H8.1, J1.1, J3.6 (VSS), J3.10 (DET_A), J3.11 (SHIELD), J5.1, J5.4, J5.7, J5.10, J5.13, J5.16, J5.19, J5.22, J5.25, J11.2 (Ext), L1.1, L4.1, L10.1, L15.1, L16.1, L17.1, M1.35 (EXT_GND), M1.CN7_8 (GND_CN7), M1.CN8_11 (GND_CN8), M1.CN8_13 (GND_CN8), M1.CN9_12 (GND_CN9), M1.CN9_23 (GND_CN9), M1.CN10_5 (GND_CN10), M1.CN10_17 (GND_CN10), M1.CN10_22 (GND_CN10), M1.CN10_27 (GND_CN10), R1.2, R2.2, R3.2, R5.2, U2.4 (GND), U3.4 (GND), U8.16 (GND), U10.5 (GND2), U12.1 (1DE), U12.6 (GND), U12.7 (GND), U12.8 (3DE), U12.12 (4DE), U12.18 (GND), U12.19 (~3RE), U12.21 (~4RE), U12.23 (GND), U12.27 (GND), U12.31 (GND), U12.34 (GND), U12.38 (GND), U12.40 (~1RE), U12.43 (GND), U12.49 (EP), U13.6 (GND), U13.7 (GND), U13.18 (GND), U13.23 (GND), U13.27 (GND), U13.31 (GND), U13.34 (GND), U13.38 (GND), U13.43 (GND), U13.49 (EP), U14.2 (V_{SS}), U18.16 (GND), U19.4 (GND), U19.5 (DIR), U20.4 (GND), U20.5 (DIR), U21.2 (GND), U22.12 (DGND), U24.2 (V-), U25.4 (VEE), U26.4 (VEE), U27.4 (VEE), U28.3 (C), U29.3 (C), U30.3 (C), U31.3 (C), U32.3 (V-), U36.3 (C), U37.2, U38.4 (VEE)
GNDA: C16.2, C17.1, C18.2, C19.1, C22.1, C25.2, C26.2, C30.1, C31.2, C32.2, C33.1, C36.2, C37.2, C39.2, C40.1, C41.2, C42.1, C43.2, C44.2, C45.2, C46.2, C47.1, C49.2, C50.2, C51.1, C52.2, C90.2, C91.1, C92.2, C93.2, C94.2, C95.2, C97.2, C98.1, C99.2, C100.2, C101.1, C102.2, C103.2, C104.2, C105.1, C106.2, C107.1, C109.2, C110.2, C111.2, C112.2, C124.2, C125.2, C127.2, C128.1, C129.1, C130.1, C131.2, C132.2, C133.2, C134.1, C135.2, D9.1 (A), D10.1 (A), D11.1 (A), D12.1 (A1), J7.5, J7.7, J12.2, J12.4, JP3.1 (A), L4.2, M1.CN10_3 (AGND_CN10), R6.2, R30.2, R42.2, R43.2, R50.1, U1.5 (COM), U4.2 (GND), U5.3 (GND), U6.4 (GND), U6.9 (EP_1), U8.1 (CHAIN), U8.3 (GND), U8.6 (GND), U8.10 (GND), U15.4 (GND), U16.2 (V-), U18.1 (CHAIN), U18.3 (GND), U18.6 (GND), U18.10 (GND), U22.3 (AGNDF), U22.4 (AGNDS)
GT0: J12.3, R47.1
unnamed: C1.1, H1.1, R1.1
unnamed: C2.1, H2.1, R2.1
unnamed: C73.1, R14.2
unnamed: C74.1, R15.2
unnamed: C38.2, D2.1 (K), D3.2 (A), R7.2, R10.1, U7.1 (-)
unnamed: C38.1, D3.1 (K), D4.2 (A), R8.2, R9.1, U7.8 (+)
unnamed: C96.2, D6.2 (A), D7.1 (K), R33.2, R37.1, U17.1 (-)
unnamed: C96.1, D7.2 (A), D8.1 (K), R34.2, R36.1, U17.8 (+)
unnamed: D12.2 (A2), R49.2, R51.1, U23.1 (-)
unnamed: D13.2 (A), J8.2 (Ext), U25.3 (C)
unnamed: D13.1 (K), R55.2, U25.1 (A)
unnamed: D14.2 (A), J9.2 (Ext), U26.3 (C)
unnamed: D14.1 (K), R56.2, U26.1 (A)
unnamed: D15.2 (A), J10.2 (Ext), U27.3 (C)
unnamed: D15.1 (K), R57.2, U27.1 (A)
unnamed: J2.1 (In), R8.1
unnamed: J4.3, U11.8 (RIN)
unnamed: J4.5, U11.13 (DOUT)
unnamed: J8.1 (In), R55.1
unnamed: J9.1 (In), R56.1
unnamed: J10.1 (In), R57.1
unnamed: J11.1 (In), R62.1
unnamed: C154.2, C155.1, C156.2, C157.2, J14.1, U36.4 (VEE)
unnamed: C154.1, C156.1, C157.1, J14.2, U36.6 (VCC)
unnamed: C155.2, J14.6, R65.1
unnamed: J14.7, R67.1
unnamed: J14.9, U37.4
unnamed: J14.13, R66.1
unnamed: J14.15, U38.3 (C)
unnamed: JP3.2 (B), PP3.1, R40.2
unnamed: PP6.1, R44.1, R46.1, U23.14
unnamed: PP7.1, R45.1, R47.2, U23.6
unnamed: Q1.4 (G), R3.1
unnamed: R48.1, R49.1, U23.15
unnamed: R52.1, R53.1, U23.7
unnamed: R62.2, U32.4
unnamed: R64.1, U37.1
unnamed: R66.2, U37.3
unnamed: C20.2, U2.6 (BST)
unnamed: C23.2, R4.2, R5.1, U2.1 (FB)
unnamed: C21.2, U3.6 (BST)
unnamed: C32.1, U6.6 (NR/SS)
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

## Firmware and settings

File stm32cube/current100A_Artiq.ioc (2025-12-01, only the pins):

Mcu.UserName=STM32H743ZITx
PA1.Signal=ETH_REF_CLK
PA2.Signal=ETH_MDIO
PA7.Signal=ETH_CRS_DV
PB0.GPIO_Label=LD1 [Green Led]
PB0.Signal=GPIO_Output
PB12.GPIO_Label=SET_RDL
PB12.Signal=GPIO_Output
PB13.Signal=ETH_TXD1
PB14.GPIO_Label=LD3 [Red Led]
PB14.Signal=GPIO_Output
PC0.GPIO_Label=L2_RIGHT
PC0.Signal=GPIO_Output
PC1.Signal=ETH_MDC
PC2_C.GPIO_Label=SET_ADC
PC2_C.Signal=SPI2_MISO
PC3_C.Signal=SPI2_MOSI
PC4.Signal=ETH_RXD0
PC5.Signal=ETH_RXD1
PD13.GPIO_Label=LEM_OK
PD13.Signal=GPIO_Input
PD3.GPIO_Label=SET_SCK
PD3.Signal=SPI2_SCK
PD4.GPIO_Label=ADC_CNV
PD4.Signal=GPIO_Output
PD6.GPIO_Label=L2_LEFT
PD6.Signal=GPIO_Output
PD7.GPIO_Label=LEM_BUSY
PD7.Signal=GPIO_Input
PD8.GPIO_Label=STLINK_RX
PD8.Signal=USART3_TX
PD9.GPIO_Label=STLINK_TX
PD9.Signal=USART3_RX
PE1.GPIO_Label=LD2 [Yellow Led]
PE1.Signal=GPIO_Output
PE11.GPIO_Label=LEM_RDL
PE11.Signal=GPIO_Output
PE12.GPIO_Label=LEM_SCK
PE12.Signal=SPI4_SCK
PE13.GPIO_Label=LEM_ADC
PE13.Signal=SPI4_MISO
PE4.GPIO_Label=SET_BUSY
PE4.Signal=GPIO_Input
PE6.Signal=SPI4_MOSI
PF6.GPIO_Label=MOS_CS
PF6.Signal=GPIO_Output
PF7.GPIO_Label=MOS_CLK
PF7.Signal=SPI5_SCK
PF9.GPIO_Label=MOS_DATA
PF9.Signal=SPI5_MOSI
PG11.Signal=ETH_TX_EN
PG13.Signal=ETH_TXD0
PG2.GPIO_Label=MOS_LDAC
PG2.Signal=GPIO_Output

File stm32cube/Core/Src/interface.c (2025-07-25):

/*
 * interface.c
 *
 *  Created on: Apr 10, 2022
 *      Author: UMK, Piotr Morzynski
 */

#include "interface.h"
#include <stdlib.h>
#include <string.h>
#include <math.h>

int rmwhite(char *str);
double atofmy(char *str);
int cmd_string_interpret(char *sin, char *sout);
int cmd_interpret(char *sin, char *ssend);

int ftostr(char *str, double val);

parameters par;

pointer getPointer(pointer p, char *s)
{
  pointer pout = {0, ""};
  if (strcmp(p.type, "parameters") == 0)
  {
    parameters *ptmp = (parameters *)p.p;
    if (strcasecmp(s, "VER") == 0)
      pout = (pointer){.p = (void *)&(ptmp->ver), .type = "value"};
    if (strcasecmp(s, "ADC") == 0)
      pout = (pointer){.p = (void *)&(ptmp->adc), .type = "adc"};
    if (strcasecmp(s, "DAC") == 0)
      pout = (pointer){.p = (void *)&(ptmp->dac), .type = "dac"};
    if (strcasecmp(s, "I") == 0)
	  pout = (pointer){.p = (void *)&(ptmp->I), .type = "value"};
    if (strcasecmp(s, "RI") == 0)
    	  pout = (pointer){.p = (void *)&(ptmp->rI), .type = "value"};
    if (strcasecmp(s, "D") == 0)
	  pout = (pointer){.p = (void *)&(ptmp->D), .type = "value"};
    if (strcasecmp(s, "DIR") == 0)
	    pout = (pointer){.p = (void *)&(ptmp->dir), .type = "value"};
    if (strcasecmp(s, "DST") == 0)
      pout = (pointer){.p = (void *)&(ptmp->dst), .type = "value"};
    if (strcasecmp(s, "MODE") == 0)
	    pout = (pointer){.p = (void *)&(ptmp->mode), .type = "value"};
    if (strcasecmp(s, "ERMAX") == 0)
	    pout = (pointer){.p = (void *)&(ptmp->ermax), .type = "value"};
    if (strcasecmp(s, "AERMAX") == 0)
      pout = (pointer){.p = (void *)&(ptmp->aermax), .type = "value"};
    if (strcasecmp(s, "GOFF") == 0)
	    pout = (pointer){.p = (void *)&(ptmp->goff), .type = "value"};
    if (strcasecmp(s, "CUR") == 0)
	    pout = (pointer){.p = (void *)&(ptmp->cur), .type = "value"};
    if (strcasecmp(s, "DCUR") == 0)
	    pout = (pointer){.p = (void *)&(ptmp->dcur), .type = "value"};
    if (strcasecmp(s, "SETA") == 0)
    	  pout = (pointer){.p = (void *)&(ptmp->setA), .type = "value"};
    if (strcasecmp(s, "LEMA") == 0)
    	  pout = (pointer){.p = (void *)&(ptmp->lemA), .type = "value"};
    if (strcasecmp(s, "VG") == 0)
    	  pout = (pointer){.p = (void *)&(ptmp->vg), .type = "value"};
    if (strcasecmp(s, "CALIB") == 0)
    	  pout = (pointer){.p = (void *)&(ptmp->calib), .type = "value"};
    if (strcasecmp(s, "LEMSH") == 0)
    	  pout = (pointer){.p = (void *)&(ptmp->lemsh), .type = "value"};
    if (strcasecmp(s, "IMAX") == 0)
    	  pout = (pointer){.p = (void *)&(ptmp->imax), .type = "value"};
    if (strcasecmp(s, "GT0") == 0)
    	  pout = (pointer){.p = (void *)&(ptmp->gt0), .type = "value"};
    if (strcasecmp(s, "GT1") == 0)
    	  pout = (pointer){.p = (void *)&(ptmp->gt1), .type = "value"};
    if (strcasecmp(s, "GT5") == 0)
    	  pout = (pointer){.p = (void *)&(ptmp->gt5), .type = "value"};
    if (strcasecmp(s, "GT10") == 0)
    	  pout = (pointer){.p = (void *)&(ptmp->gt10), .type = "value"};
    if (strcasecmp(s, "SAVE") == 0)
    	  pout = (pointer){.p = (void *)&(ptmp->save), .type = "value"};
    if (strcasecmp(s, "LOAD") == 0)
        pout = (pointer){.p = (void *)&(ptmp->load), .type = "value"};
    if (strcasecmp(s, "VERREAD") == 0)
        pout = (pointer){.p = (void *)&(ptmp->veread), .type = "value"};
  }

  if (strcmp(p.type, "adc") == 0)
  {
    sadc *ptmp = (sadc *)p.p;
    if (strcasecmp(s, "CH1") == 0)
      pout = (pointer){.p = (void *)&(ptmp->ch1), .type = "adcchannel"};
    if (strcasecmp(s, "CH2") == 0)
      pout = (pointer){.p = (void *)&(ptmp->ch2), .type = "adcchannel"};
  }
  if (strcmp(p.type, "adcchannel") == 0)
  {
    sadcchannel *ptmp = (sadcchannel *)p.p;
    if (strcasecmp(s, "RAW") == 0)
          pout = (pointer){.p = (void *)&(ptmp->raw), .type = "value"};
    if (strcasecmp(s, "VOLT") == 0)
      pout = (pointer){.p = (void *)&(ptmp->volt), .type = "value"};
    if (strcasecmp(s, "AVR") == 0)
      pout = (pointer){.p = (void *)&(ptmp->avr), .type = "value"};
    if (strcasecmp(s, "CORON") == 0)
      pout = (pointer){.p = (void *)&(ptmp->coron), .type = "value"};
    if (strcasecmp(s, "CORFACTOR") == 0)
      pout = (pointer){.p = (void *)&(ptmp->corfactor), .type = "value"};
  }

  if (strcmp(p.type, "dac") == 0)
    {
      sdac *ptmp = (sdac *)p.p;
      if (strcasecmp(s, "CH1") == 0)
        pout = (pointer){.p = (void *)&(ptmp->ch1), .type = "dacchannel"};
    }

  if (strcmp(p.type, "dacchannel") == 0)
    {
      sdacchannel *ptmp = (sdacchannel *)p.p;
      if (strcasecmp(s, "RAW") == 0)
            pout = (pointer){.p = (void *)&(ptmp->raw), .type = "value"};
      if (strcasecmp(s, "VOLT") == 0)
        pout = (pointer){.p = (void *)&(ptmp->volt), .type = "value"};
    }

  if (strcmp(p.type, "value") == 0)
  {
    value *ptmp = (value *)p.p;
    if (strcasecmp(s, "VAL") == 0)
      pout = (pointer){.p = (void *)&(ptmp->val), .type = "double"};
    if (strcasecmp(s, "MIN") == 0)
      pout = (pointer){.p = (void *)&(ptmp->min), .type = "double"};
    if (strcasecmp(s, "MAX") == 0)
      pout = (pointer){.p = (void *)&(ptmp->max), .type = "double"};
    if (strcasecmp(s, "TABON") == 0)
      pout = (pointer){.p = (void *)&(ptmp->tabon), .type = "ison"};
    if (strcasecmp(s, "MES") == 0)
      pout = (pointer){.p = (void *)&(ptmp->mes), .type = "mestab"};
  }

  if (strcmp(p.type, "mestab") == 0)
  {
    mestab *ptmp = (mestab *)p.p;
    if (strcasecmp(s, "SIZE") == 0)
      pout = (pointer){.p = (void *)&(ptmp->tabsize), .type = "int"};
    if (strcasecmp(s, "COUNT") == 0)
      pout = (pointer){.p = (void *)&(ptmp->tabcount), .type = "int"};
    if (strcasecmp(s, "POS") == 0)
      pout = (pointer){.p = (void *)&(ptmp->tabpos), .type = "int"};
  }
  if (strcmp(p.type, "ison") == 0)
  {
    ison *ptmp = (ison *)p.p;
    if (strcmp(s, "IS") == 0)
      pout = (pointer){.p = (void *)&(ptmp->is), .type = "int"};
  }
  return pout;
}

void setParam(value *p, double val)
{
  if (val > p->max)
    val = p->max;
  if (val < p->min)
    val = p->min;
  p->val = val;

  if (p->tabon.is == 1 && p->mes.ptab[0] != 0 && p->mes.ptab[0] != 0)
  {
    ((p->mes.ptab)[p->mes.tabcount % 2])[p->mes.tabpos] = val;
    p->mes.tabpos++;
    if (p->mes.tabpos > p->mes.tabsize - 1)
    {
      p->mes.tabpos = 0;
      p->mes.tabcount++;
    }
  }
}
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

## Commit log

2024-08-12 adding kicad project made by ALe
    [Power_supply.kicad_sch, analog_input.kicad_sch, artiq_base.FCStd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]
2024-08-12 created stm32cube project based on ioc file from kicad
2024-08-13 added rtos, tests on uart3 and ld1 blink in separate tasks
2024-09-08 works on adc, initially works for adc-set, but need to be tested
2024-09-10 adc lem and set initial calibration
2024-09-12 first simple pid only with I
2024-09-23 remove stm32cube because of problem with git submodule
2024-09-23 added stm32cube without .git
2024-09-25 adding spi2 - adc-set, (eth works)
2024-09-25 adding spi4-lem-adc, changed device name in eth console
2024-09-26 adcs works, but not well calibrated
2024-09-30 adding I to menu, pid cycle = 500us
2024-11-28 setting server ip from gnetif, switching to dhcp mode
2024-12-15 setting L2 current direction based on parameter DIR
2024-12-15 lema and seta calibration for tock driver
2025-01-02 adding calibration procedure - not tested yet
2025-01-02 cycle set to 200us, switching ld1 using registers (not HAL)
2025-01-02 switching directions coils using registers instead of hal
2025-01-05 smoth current change using ermax
2025-01-21 working on g_tab if filled with zeros
    [current100A_Artiq Debug.cfg]
2025-02-14 bugfix: driver for 4th T, capacitors for input amps
    [Power_supply.kicad_sch, analog_input.kicad_sch, current100A_Artiq.kicad_pcb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]
2025-05-28 comments, cleaning, removing wrong pid_out limits
    [main.c]
2025-06-11 working on direction switching - just current limit
2025-06-11 switching direction using negative set_A
